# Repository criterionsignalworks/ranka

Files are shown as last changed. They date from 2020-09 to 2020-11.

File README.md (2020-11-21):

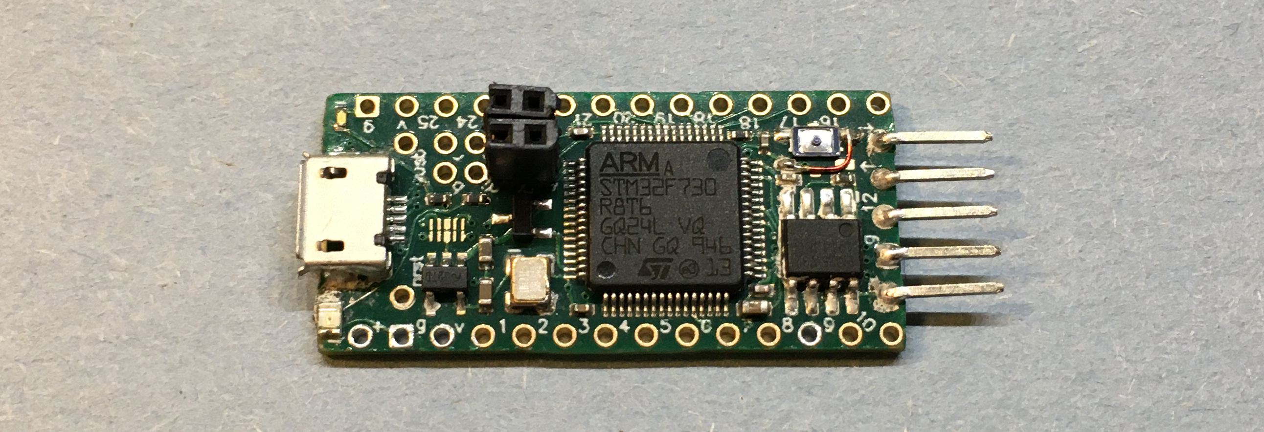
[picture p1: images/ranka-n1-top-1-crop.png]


# Overview

CS Ranka is a performant, flexible, and economical development platform for the STM32F7 series of microcontrollers.

We selected the [STM32F730](https://www.st.com/en/microcontrollers-microprocessors/stm32f730r8.html) in LQFP64 package with its minimal internal flash to reduce cost, while simultaneously maintaining the performance and flexibility of other chips in the family by featuring the same Cortex-M7 core and on-board USB HS physical layer. [A low cost 32Mbit serial flash chip](http://www.fmsh.com/nvm/FM25W32_ds_eng.pdf) is included which adds to internal flash of the F730, creating a more cost-effective solution.

The formfactor of Ranka N1 is loosely based off of [Teensy](https://www.pjrc.com/teensy/), and parallels Arduino Nano. Great care has been taken to select breakout pins that expose the most peripheral ports for maximized flexibility and capability. Our design makes available 5 serial ports (3 are USARTs), 2 SPI resources, 3 I2C resources, 10 ADC pins, 1 CAN bus, and USB HS through micro-B connector (FS/HS selectable via jumper). The increased communication interfaces on board make Ranka N1 more versatile than most other devices of its formfactor. (Arduino Nano/Uno, Teensy 4.0/3.2, Maple Mini/Blue Pill, NodeMCU, Feather 32u4, just to name a few). Combined with compute performance that is only bested by the iMX RT1062 chip aboard [Teensy 4.0](https://www.pjrc.com/store/teensy40.html), Ranka N1 is an excellent choice for projects that demand more performance than an Arduino Nano or Maple Mini, while keeping cost at top priority.

# Design Choices

Originally, we intended to use the QUADSPI port for communicating with the external serial flash. However, data pin 2 was not present on the LQFP64 package of STM32F730, so we instead reserved F730's third SPI resource exclusively for use with flash. (using SPI3 would cause problems later, actually)
 
Solderable jumpers on the bottom of the device allow users the option to decide if they would like VUSB disconnected from VIN. Additional jumpers on D+ and D- lines of the USB micro-B connector are wired to the USB FS pins by default. Users may cut the default net tie and solder bridge the USB HS data pins if they wish to sacrifice SPI2's functionality for improved data transmission rates.

We chose a [25MHz oscillator](https://lcsc.com/product-detail/SMD-Oscillators-XO_EPSON_Q33310F70032100_SG-310SCF-25MHZ-3-3V-40-85_C32526.html) as per ST recommendations for best stability of high-speed peripherals. Supply decoupling capacitors were included as well for improved stability. The current revision of Ranka N1 does not feature a dedicated analog power section, as there is not enough physical space for two power supply sections due to process limitations. Since the MCU is an LQFP package, it's technically possible to solder to the pins directly if a dedicated analog supply section is desired.

# Realization

ST provided sample [STM32F746NG](https://estore.st.com/en/stm32f746ngh6-cpn.html) chips for evaluation. Since we do not have any breakout boards for the BGA package, we made Ranka N0.1 and N0.2 using dead bug prototyping method to begin developing software targeting STM32F7 devices. As you can see, the result isn't too elegant:

Image of Ranka N0.5 prototype

Schematic of minimal components specifically for the microcontroller is derived from [ST's documentation](https://www.st.com/resource/en/application_note/dm00164549-getting-started-with-stm32f7-series-mcu-hardware-development-stmicroelectronics.pdf). Rail regulation and protection consist of a reverse blocking P channel enhancement mode MOSFET and a low dropout regulator selected mostly for efficiency. We omitted TVS diodes or current limiting on VIN due to space limitations with our current process.

The board is routed according to design rules based on JLCPCB's [capabilities](https://jlcpcb.com/capabilities/Capabilities). We chose to use any-angle/topographical routing for Ranka N1 primarily for improved efficiency and aesthetics. While any-angle routing is superior to conventional methods, we are still in the experimentation phase and will continue to perfect our designs in upcoming revisions.

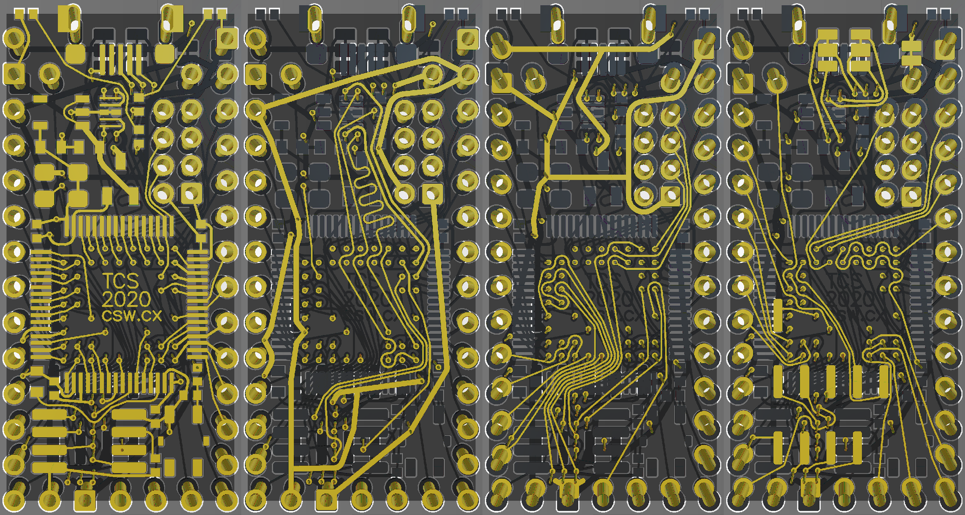
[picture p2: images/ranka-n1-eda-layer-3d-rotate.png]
Image of routed layers in EDA


# Results

The physical boards were fabricated and assembled without issues. External flash chip, user button, and micro-USB type B port required manual soldering as they are not available for SMT assembly service. Buttons of the exact footprint had not been acquired, so a bodge was done for prototyping.

Our expectations were met after initial testing with power rail measurements and software toolchain demos. Using STM32CubeMX init code generator and HAL quick start code, we successfully blinked the user LED on board.

# Revision Opportunities
Choosing SPI3 for boot loading from flash seemed to be a bad idea. We did not consider the possibility that the specific peripheral device would not support boot loading like SPI1, 2, or QUADSPI. One possible workaround to this issue is to manually wire SPI1 pins to the external flash footprint from broadside pin headers. DAC and four analog channels would be occupied by the on-board external flash. This would not be feasible for production/release but will be adequate for prototyping.

The debug connectors certainly could be designed better. 2x4 array of through hole headers with a pitch of 2mm proved to be difficult to work with. Perhaps consider aligning SWD pins in one column for future designs, so a much less complex programming harness and receptacle may be utilized.

Additionally, there was a mistake with the pin numbering on the top side silkscreen. Pin 18 was counted twice and numbers after 18 are offset by one. It doesn't affect functionality in any way, aside from being inconvenient and annoying. 

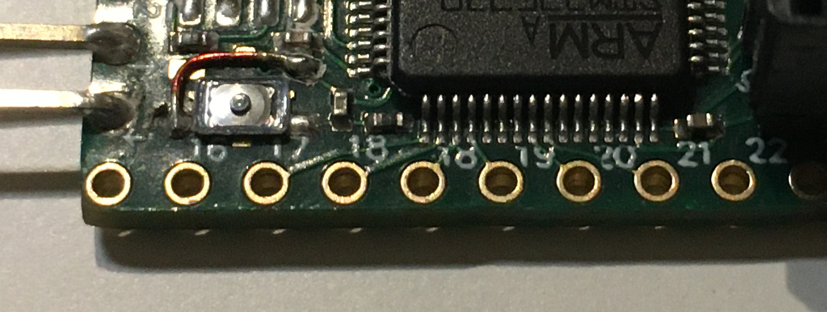
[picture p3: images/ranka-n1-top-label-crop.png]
Image of mislabeled pins


# Future Plans

We plan to use Ranka N1 as a starting point for our projects using the STM32 series of microcontrollers. In the future, we plan to produce development boards targeting the STM32MP1 microprocessor lineup, as they offer very high compute performance.

We may produce another revision of these boards targeting the same STM32F730 microcontroller, addressing the flaws presented, however our development efforts may be better spent pursuing alternate solutions and platforms, as the main goals of Ranka N1 include process demonstration and familiarization.

## JLCPCB

We want to briefly acknowledge support from [JLCPCB](https://jlcpcb.com/) as they have made this whole project possible. Previously, when we were still learning to create PCBs, JLCPCB customer assurance supported us and would always notify us if there was a problem with our board. This was extremely helpful and the combined flexibility and cost savings JLCPCB offers has kept us grateful for their efforts to inspire hobbyists like us.

After ordering approximately 500 PCBs for numerous projects, JLCPCB has consistently offered quick and easy customer support, affordable prices, and plenty of flexibility for a wide range of products. We recommend it to any hobbyist trying to create their personal circuit boards.

# License
This work is licensed under a [Creative Commons Attribution-NonCommercial-ShareAlike 4.0 International License][cc-by-nc-sa].

[cc-by-nc-sa]: http://creativecommons.org/licenses/by-nc-sa/4.0/

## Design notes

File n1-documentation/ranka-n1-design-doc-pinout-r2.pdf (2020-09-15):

CS Ranka N1 Pinout Map
CSW.cx - TCS 2020
Preliminary r 2.23
Physical

Physical

N

RST

V

USB
USB | Resources
Vin | V R | V G | GND | 4 | Serial
GND | G

D

B

G

V | 3V3 | 2 | SPI
3V3 | V | 62 | PB9 | TX1 | 3 | I2C
RTC | PC13 | 2 | 61 | PB8 | RX1 | 1 | CAN
A0 | TX4 | PA0 | 14 | 59 | PB7 | RX1 | SDA1 | 10 Analog
A1 | RX4 | PA1 | 15 | 58 | PB6 | TX1 | SCL1
A2 | TX2 | PA2 | 16 | 41 | PA8 | CK1 | SCL3
A3 | RX2 | PA3 | 17 | 40 | PC9 | SDA3
!
DAC1 | A4 | CS1 | CK2 | PA4 | 20 | 36 | PB15 | MOSI2
DAC2 | A5 | CK1 | PA5 | 21 | 35 | PB14 | RTS3 | MISO2
A6 MISO1 | PA6 | 22 | 34 | PB13 | CTS3 | CK2
A7 MOSI1 | PA7 | 23 | 33 | PB12 | CK3 | CS2
A8 | PB0 | 25 | 29 | PB11 | RX3 | SDA2
A9 | PB1 | 26 3 G 39 38 37 28 | PB10 | TX3 | SCL2

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
DBG | Flash | Breakout
GND | G | 3 | 3V3 | 50 | PA15 CS3 | BTN PB5 | 57 | 27 | PB2 LED
46 SWIO | IO | CK | SWCK 49 | 51 | PC10 CK3 | PA10 | 43 | 11 | PC3
55 JTDO | O | I | JTDI 50 | 52 | PC11 MISO3 | PA9 | 42 | 10 | PC2
56 NRST | R | B | Boot0 60 | 53 | PC12 MOSI3 | PC4 | 24 | 9 | PC1
Flash Control | USB | PC14 | 3 | 8 | PC0
F-HD | PD2 | 54
| | | D-
35 | PB14 HS Optional | PC15 | 4 | VB | VBAT
44 | PA11 FS | Default

D

+

36 | PB15 HS Optional
45 | PA12 FS | Default

Name

(FA

R)

Name

(FA

R)

OTG
HS

On board

Flash

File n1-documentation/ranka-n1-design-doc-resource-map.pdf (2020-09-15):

STM32F730R8T6 Resource Map CSW.cx - TCS 2020

Pin Name/FAR(A)FunctionI/O | Misc | Timer [TIM] | Serial
1 | VBAT | RTC
2 | PC13 | RTC | 5VT | RTC_TAMP1/TS/OUT
3 PC14-OSC32_IN | 5VT
4PC15-OSC32_OUT | 5VT
5 PH0-OSC_IN | 5VT
6 PH1-OSC_OUT | 5VT
7 | NRST | RST
8 | PC0 | 5VT
9 | PC1 | 5VT | TRACED0
10 | PC2 | 5VT
11 | PC3 | 5VT
12 | VSSA | GND
13 | VREF+ | S?
14 PA0-WKUP | 5VT | WKUP1 | 2_CH1/ETR, 5_CH1, 8_ETR USART2_CTS, UART4_TX
15 | PA1 | 5VT | | 2_CH2, 5_CH2 | USART2_RTS, UART4_RX
16 | PA2 | 5VT | WKUP2 | 2_CH3, 5_CH3, 9_CH1 | USART2_TX
17 | PA3 | 5VT | | | USART2_RX
18 | VSS | GND
19 | VDD | 3V3
20 | PA4 | ADC | | | USART2_CK
21 | PA5 | ADC | | 2_CH1/2_ETR, 8_CH1N
22 | PA6 | 5VT | | 1 8_BKIN, 3 13_CH1
23 | PA7 | 5VT | | 1 8_CH1N, 3_CH2, 14_CH1
24 | PC4 | 5VT
25 | PB0 | 5VT | | 1 8_CH2N, 3_CH3 | UART4_CTS
26 | PB1 | 5VT | | 1 8_CH3N, 2_CH4
27 | PB2 | 5VT
28 | PB10 | 5VTf | | 2_CH3 | USART3_TX
29 | PB11 | 5VTf | | 2_CH4 | USART3_RX
30 | VCAP_1 | S?
31 | VSS | GND
32 | VDD | 3V3
33 | PB12 | 5VT | | 1_BKIN | USART3_CK
34 | PB13 | 5VT | | 1_CH1N | USART3_CTS
35 | PB14 | 5VT | | 1 8_CH2N, 12_CH1 | USART3_RTS
36 | PB15 | 5VT | RTC_REFIN | 1 8_CH3N, 12_CH2
37 | PC6 | 5VT | | 3 8_CH1, | USART6_TX
38 | PC7 | 5VT | | 3 8_CH2 | USART6_RX
39 | PC8 | 5VT | TRACED1 | 3 8_CH3 | UART5_RTS, USART6_CK

40 | PC9 | 5VTf | MCO2 | 3 8_CH4 | UART5_CTS
41 | PA8 | 5VTf | MCO1 | 1_CH1, 8_BKIN2 | USART1_CK
42 | PA9 | 5VT | | 1_CH2 | USART1_TX
43 | PA10 | 5VT | | 1_CH3 | USART1_RX
44 | PA11 | 5VT | | 1_CH4 | USART1_CTS
45 | PA12 | 5VT | | 1_ETR | USART1_RTS
46 | PA13 | 5VT | JTMS-SWDIO
47 | VSS | GND
48 | VDD | 3V3
49 | PA14 | 5VT | JTCK-SWCLK
50 | PA15 | 5VT | JTDI | 2_CH1/ETR | UART4_RTS
51 | PC10 | 5VT | | | USART3_TX, UART4_TX
52 | PC11 | 5VT | | | USART3_RX, UART4_RX
53 | PC12 | 5VT | TRACED3 | | USART3_CK, UART5_TX
54 | PD2 | 5VT | TRACED2 | 3_ETR | UART5_RX
55 | PB3 | 5VT | JTDO/TRACESWO | 2_CH2
56 | PB4 | 5VT | NJTRST | 3_CH1
57 | PB5 | 5VT | | 3_CH2
58 | PB6 | 5VTf | | 4_CH1 | USART1_TX
59 | PB7 | 5VTf | | 4_CH2 | USART1_RX
60 | BOOT | B
61 | PB8 | 5VTf | | 4_CH3, 10_CH1
62 | PB9 | 5VTf | | 4_CH4, 11_CH1
63 | VSS | GND
64 | VDD | 3V3

Resources
[SPI] | [I2C] | [CAN] | [SAI] | Analog [ADC] | USB [OTG_]
| 2_FS_B 123_IN10 HS_ULPI_STP
2_MOSI/I2S2_SD | | 1_SD_A 123_IN11
2_MISO 2_MOSI/I2S2_SD | | 123_IN12 HS_ULPI_DIR 123_IN13 HS_ULPI_NXT
| 2_SD_B 123_IN0
QUAD_BK1_IO3 | | 2_MCK_B 123_IN1
| | 2_SCK_B 123_IN2
| 123_IN3 HS_ULPI_D0
13_NSS/I2S13_WS 1_SCK/I2S1_CK | | 12_IN4, DAC1 HS_SOF 12_IN5, DAC2 HS_ULPI_CK
1_MISO 1_MOSI/I2S1_SD I2S1_MCK | | 12_IN6 12_IN7 12_IN14
| | 12_IN8 HS_ULPI_D1 12_IN9 HS_ULPI_D2
3_MOSI/I2S3_SD, QUAD_CLK | | 1_SD_A
2_SCK/I2S2_CK 2_SCL | | HS_ULPI_D3
| 2_SDA | | HS_ULPI_D4
2_NSS/I2S2_WS 2_SMBA | HS_ULPI_D5, ID
2_SCK/I2S2_CK 2_MISO 2_MOSI/I2S2_SD | HS_ULPI_D6, VBUS HS_DM HS_DP

I2S2_MCK I2S3_MCK

QUAD_BK1_IO0, I2S_CKIN 3_SDA
| 3_SCL | FS_SOF
2_SCK/I2S2_CK 3_SMBA | | FS_VBUS
| | FS_ID
| 1_RX | FS_DM
| 1_TX 2_FS_B | FS_DP

1 3_NSS/I2S1 3_WS 3_SCK/I2S3_CK, QUAD_BK1_IO1 3_MISO, QUAD_BK2_NCS 3_MOSI/I2S3_SD 1 3_SCK/I2S1 3_CK 1 3_MISO, 2_NSS/I2S2_WS

1 3_MOSI/I2S1 3_SD 1_SMBA | | HS_ULPI_D7
QUAD_BK1_NCS 1_SCL
| 1_SDA
| 1_SDA 1_RX
2_NSS/I2S2_WS | | 1_TX

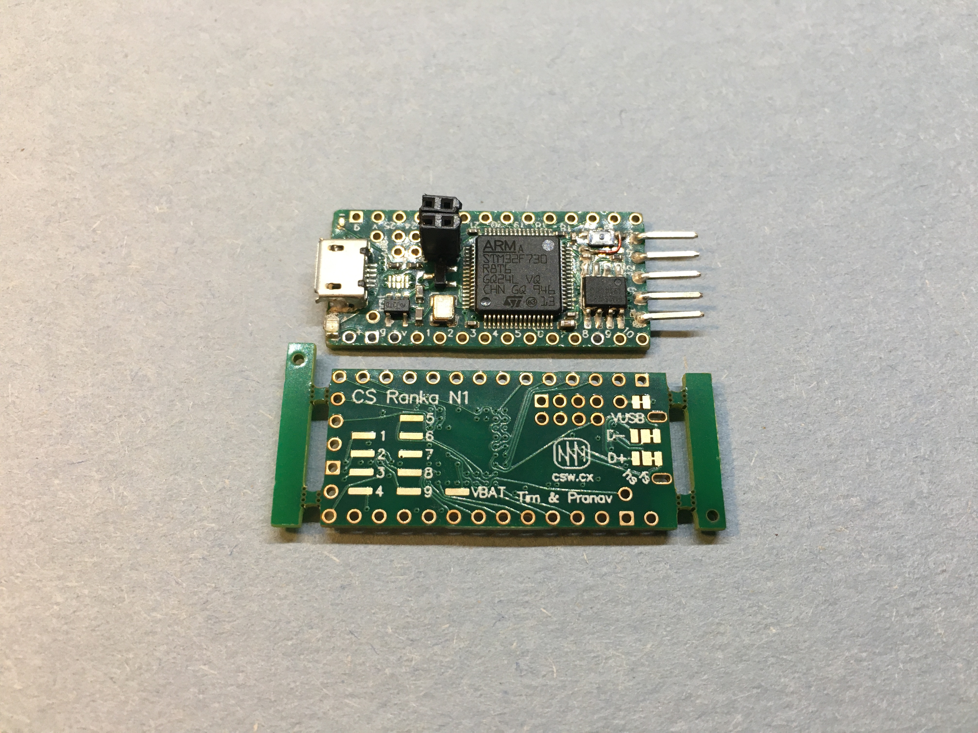
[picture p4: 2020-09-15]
images/ranka-n1-top-bottom.jpg

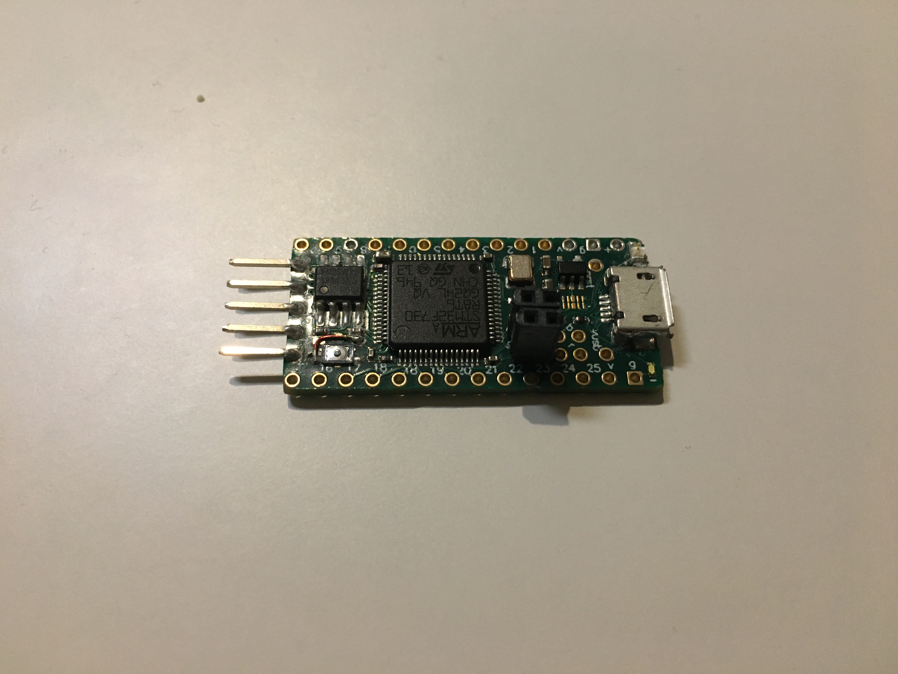
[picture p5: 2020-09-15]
images/ranka-n1-top-label.jpg

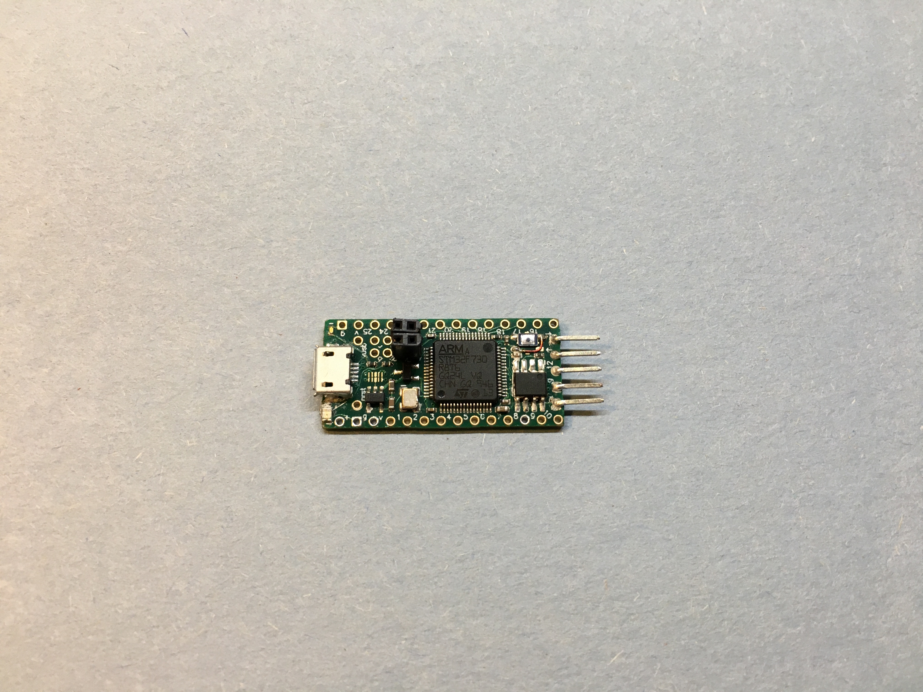
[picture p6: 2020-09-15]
images/ranka-n1-top-2.jpg

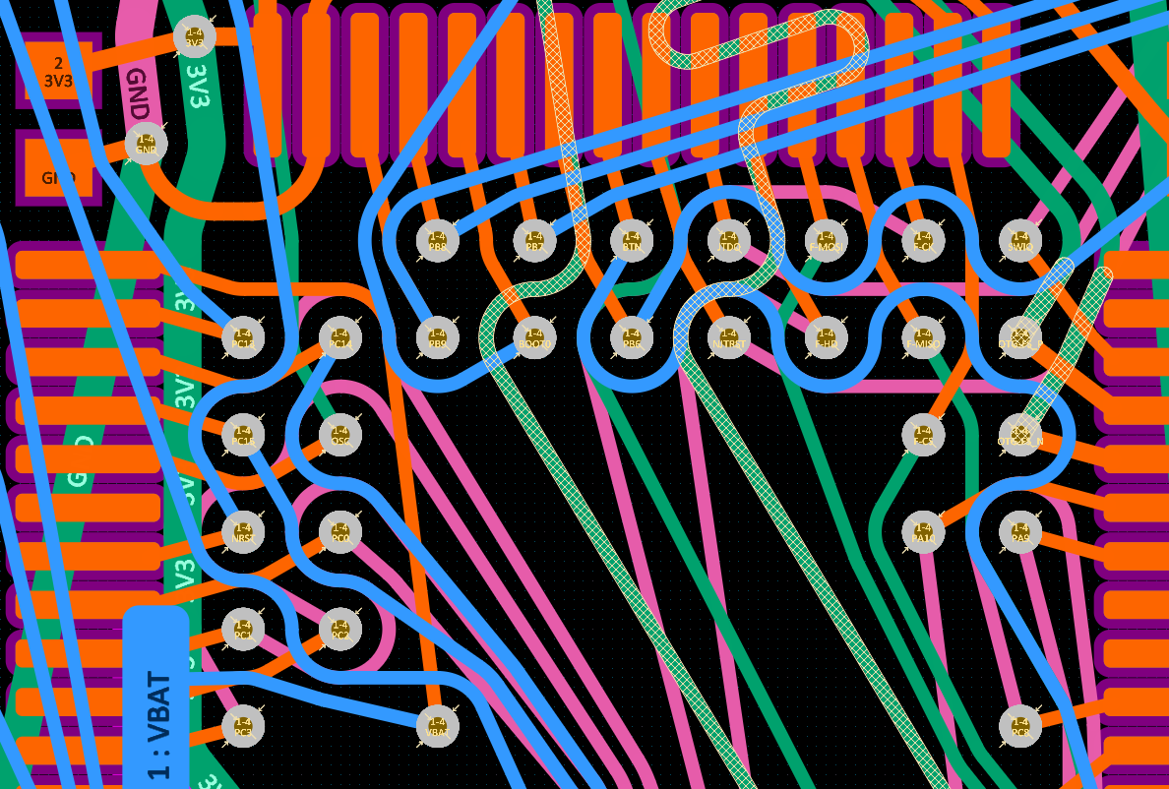
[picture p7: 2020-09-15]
images/ranka-n1-eda-1.png

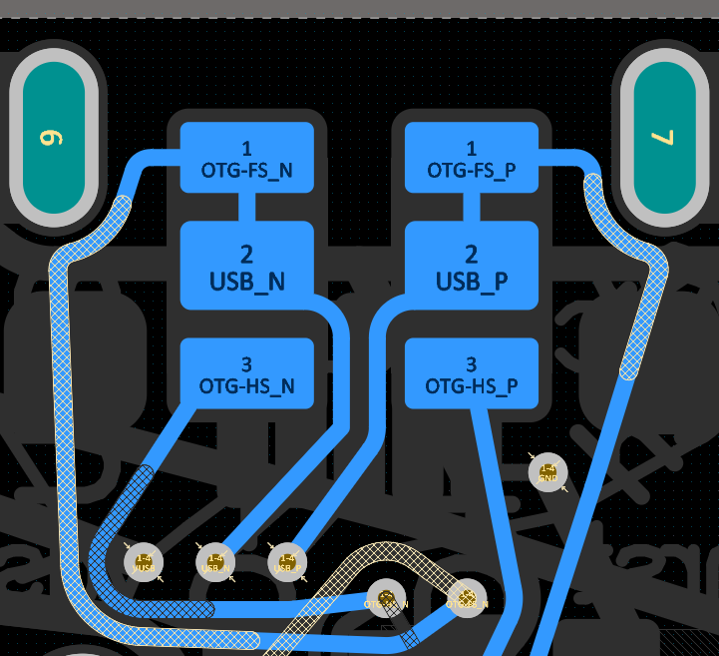
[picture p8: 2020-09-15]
images/ranka-n1-eda-3-usb.png

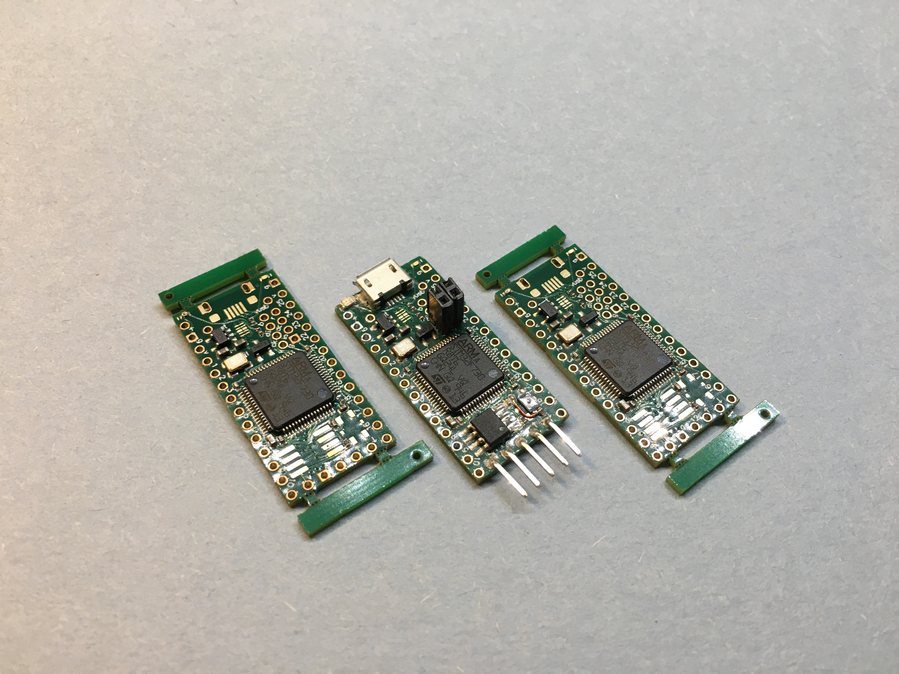
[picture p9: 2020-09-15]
images/ranka-n1-3assy.jpg

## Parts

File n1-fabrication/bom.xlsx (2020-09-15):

Part | Description | Designator | Quantity | LCSC Part #
ME6217C33M5G | Regulator | U3 | 1 | C427602
0402 Resistor | 1k | R1, R2, R3 | 3
0402 Resistor | 100 | R4 | 1
AZ1045 | TVS array | DA1 | 1 | C356811
0402 Capacitor | 100nF | C2, C3, C4, C5, C8 | 5
0603 Capacitor | 4.7uF | C1 | 1
0603 Capacitor | 10 uF | C6, C7 | 2
NCE3407 | Reverse blocking MOSFET | RB1 | 1 | C113770
FM25W32 | Flash | U2 | 1 | C431483
STM32F730R8T6 | Microcontroller | U1 | 1 | C478453
Q33310F70032100 | XO | XO1 | 1 | C32526
0402 LED | Red | D1 | 1 | C74339
0402 LED | White | D2 | 1 | C74342

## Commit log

2020-09-15 Gerber files for Ranka N1
    Final gerber files that were sent to production (202008-A)
    [bom.xlsx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]
2020-09-15 Ranka N1 layout and design docs
    [CS Ranka AB.PcbDoc]
2020-09-15 Images of fabricated boards N1
2020-09-15 Crop Ranka N0.5 prototype image
2020-09-15 Add image for Ranka N0.5 prototype
